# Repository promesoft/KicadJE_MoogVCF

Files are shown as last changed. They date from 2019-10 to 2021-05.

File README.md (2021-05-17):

# KicadJE_MoogVCF
Based on https://www.yusynth.net/Modular/Commun/MOOGVCF/Moogfilter-sch.jpg

Based on https://www.yusynth.net/Modular/Commun/WAVEFOLDER/new/JHWavefolder-sch.gif

Based on https://www.yusynth.net/Modular/Commun/ADSR/ADSR555-FINAL.gif

# Status - PCB  in the mail
## Initial 
| Stage  | Detail | Status |
| --- | --- | --- |
| create material  | sch/pcb | OK  |
| | gerber | OK |
| production  | | Ok |
|  | produced | OK |
|  | delivered | Ok |
## Preliminary validation
| Test  | Detail | Status |
| --- | --- | --- |
| Initial Inspection | | OK - silk messed a bit |
| Initial Technical Test | VCF | CV2 signal issue round Jack |
| Initial Technical Test | ADSR | OK |
| Initial Technical Test | WaveFolder | OK |
| Initial Product Test | VCF | Not working due to missing Caps |
| Initial Product Test | ADSR | OK |
| Initial Product Test | Wavefolder | Works nicely |

## Secondary validation
| Test  | Detail | Status |
| --- | --- |--- |
| Product Test | CF | VCF - working ok after botch'ed caps added - no self osc|
| Product Test | ADSR | Works fine after added 100k resistors instead of 0R across 100KB pots |
| Product Test | Wavefolder | nice - no adjustments |
| Quality | VCF | Needs tweaking |
| Quality | ADSR | ADSR interacts when turned all the way down|
| Quality | Wavefolder| Nice |
| Long Term Product Test |  |  |
| Power Draw | VCF | 24mA |
| Power Draw | ADSR | mA |
| Power Draw | Wavefolder | 7mA |

## Errata
### Errata - VCF
 * Missing signal path for CV2 on PCB
 * Missing 2 caps from C207 to R226/227

## Issues and Notes
### VCF
* C214 should be 1206 (its a bit difficult to find 22u 0805 in 16v)
* C211 and C212 should be 1206 or bigger (10u 16v potentially sounds better than 0805)

# Pictures
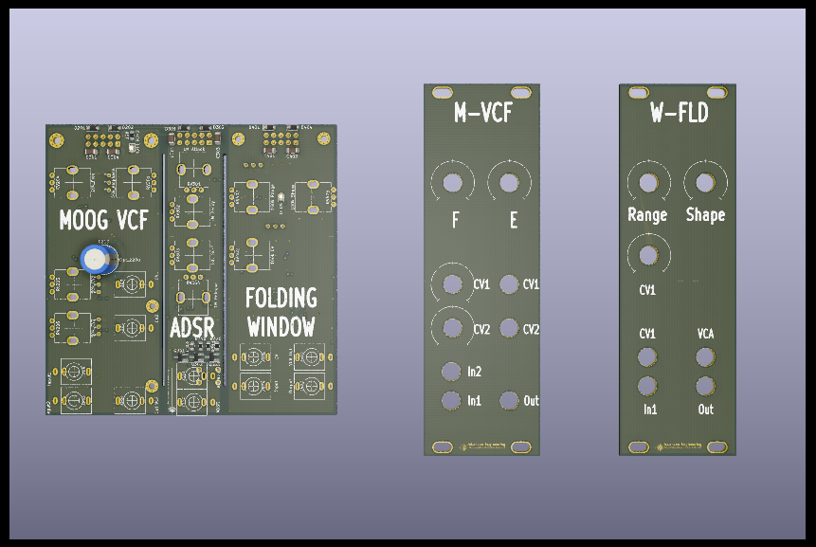
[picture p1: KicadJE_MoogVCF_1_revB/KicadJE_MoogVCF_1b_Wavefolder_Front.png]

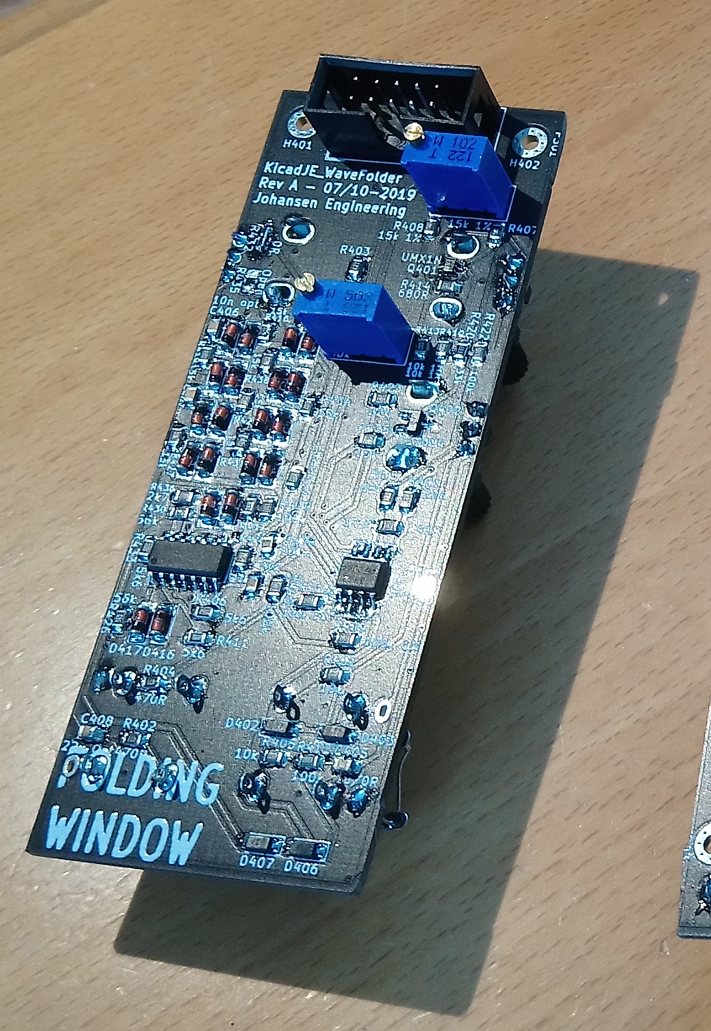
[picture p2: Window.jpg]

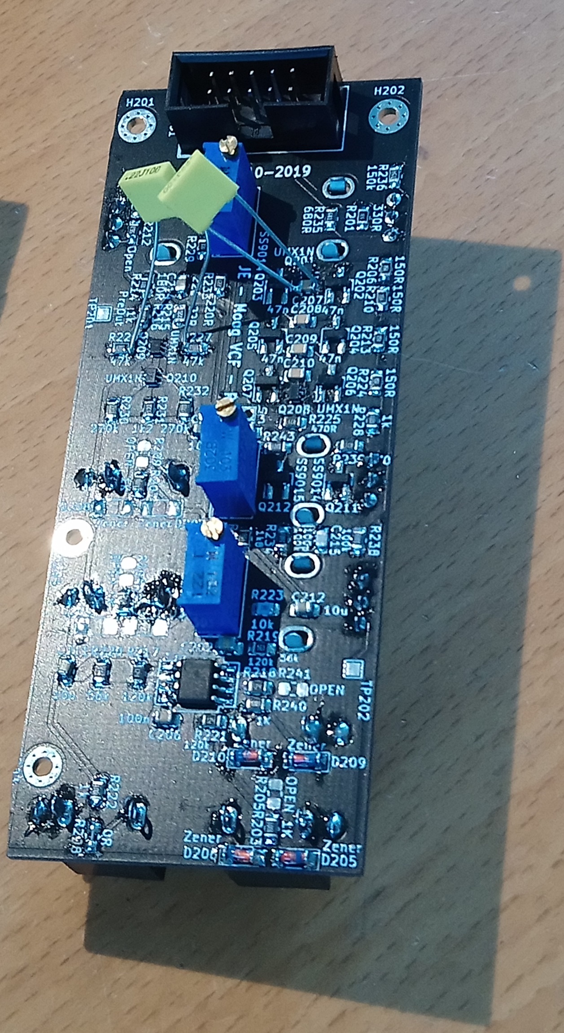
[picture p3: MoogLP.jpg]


# Inspiration

# Schematic
## Ladder Filter
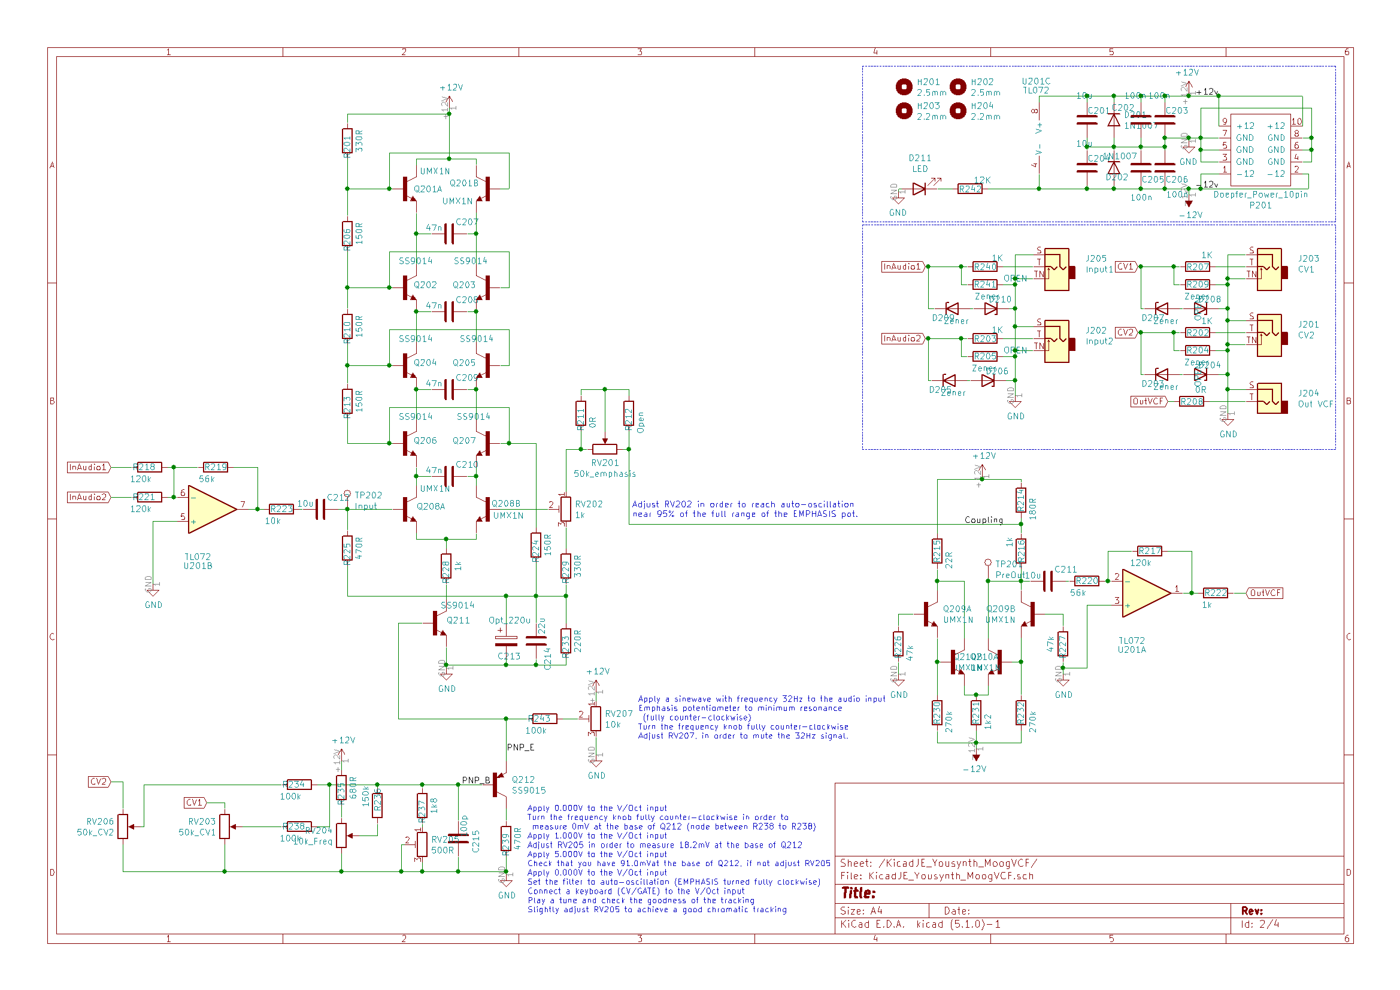
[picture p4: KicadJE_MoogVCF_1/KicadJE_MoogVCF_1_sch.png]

## Simple 555 ADSR
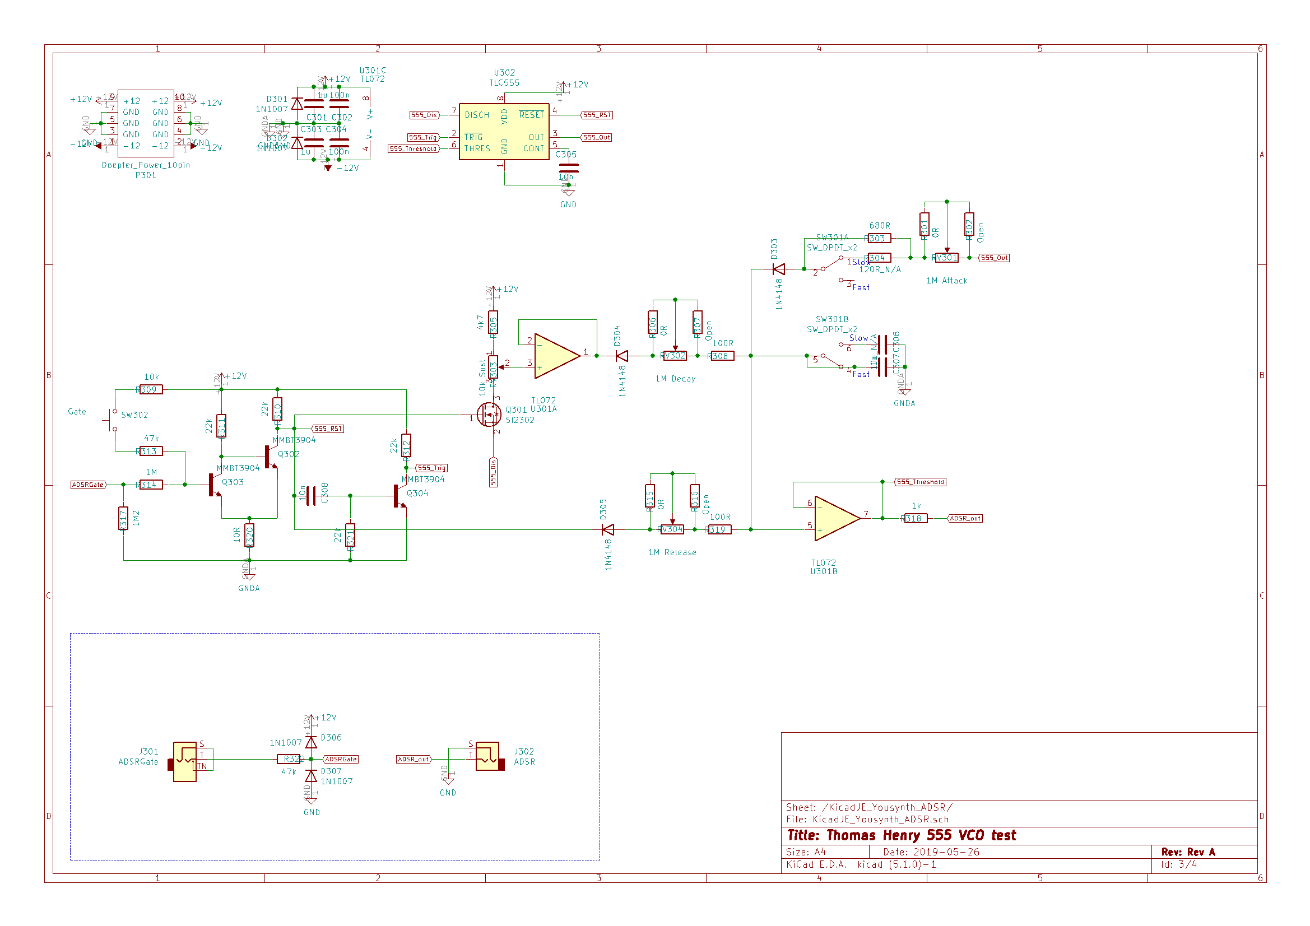
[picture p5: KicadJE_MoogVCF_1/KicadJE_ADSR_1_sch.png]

## WaveFolder
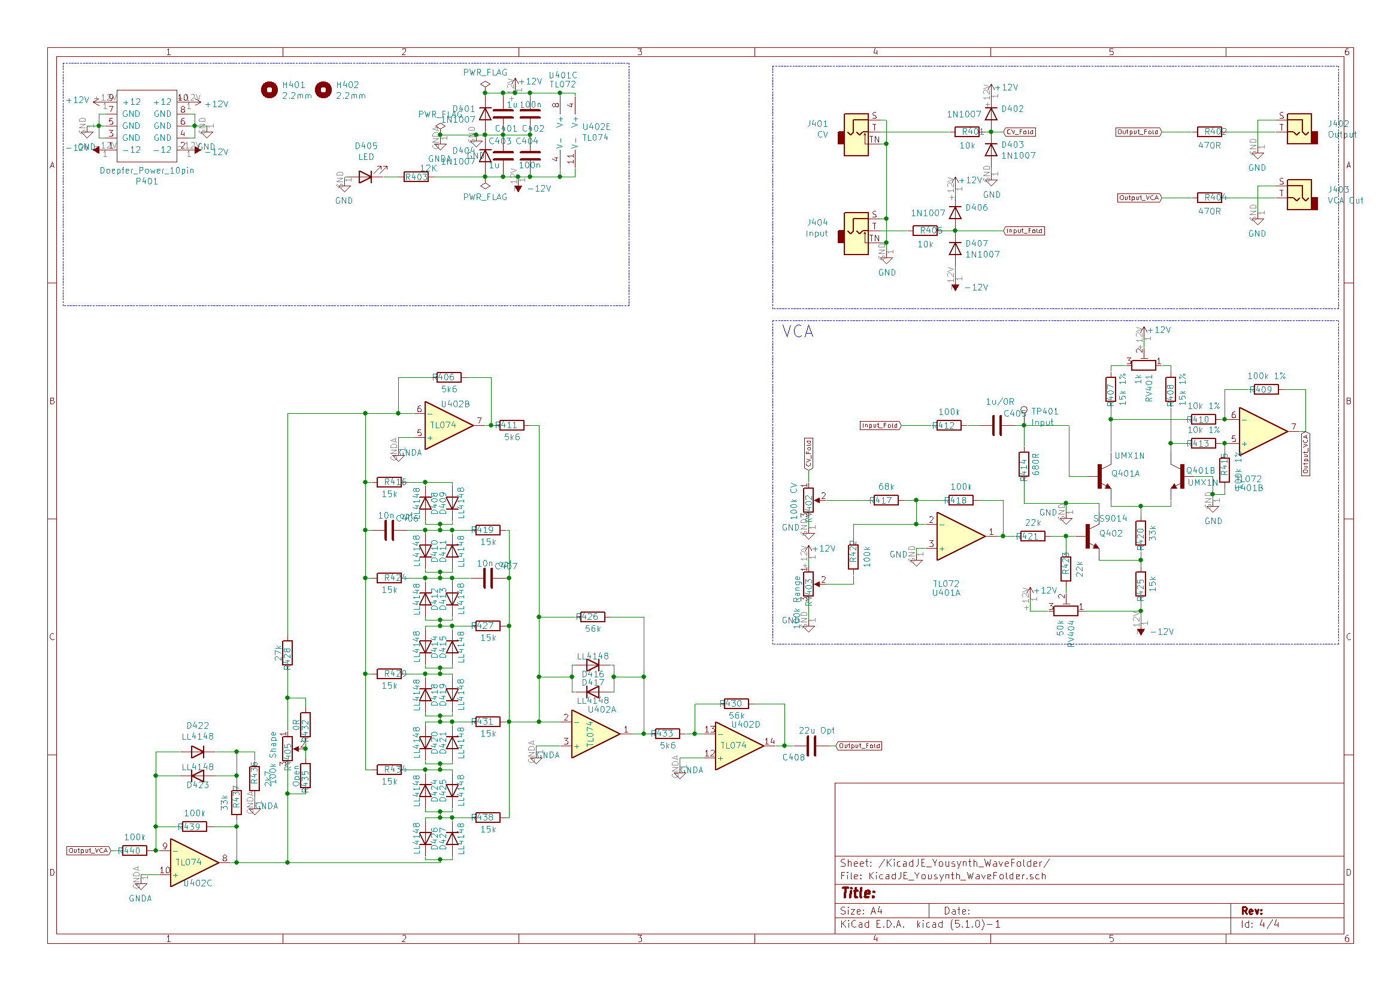
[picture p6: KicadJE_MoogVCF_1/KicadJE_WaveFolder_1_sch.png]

# Inspiration
 http://jhaible.com/legacy/jh_shaper_B.pdf
 
 https://www.yusynth.net/Modular/Commun/WAVEFOLDER/new/JHWavefolder-sch.gif

 https://www.yusynth.net/Modular/Commun/MOOGVCF/Moogfilter-sch.jpg

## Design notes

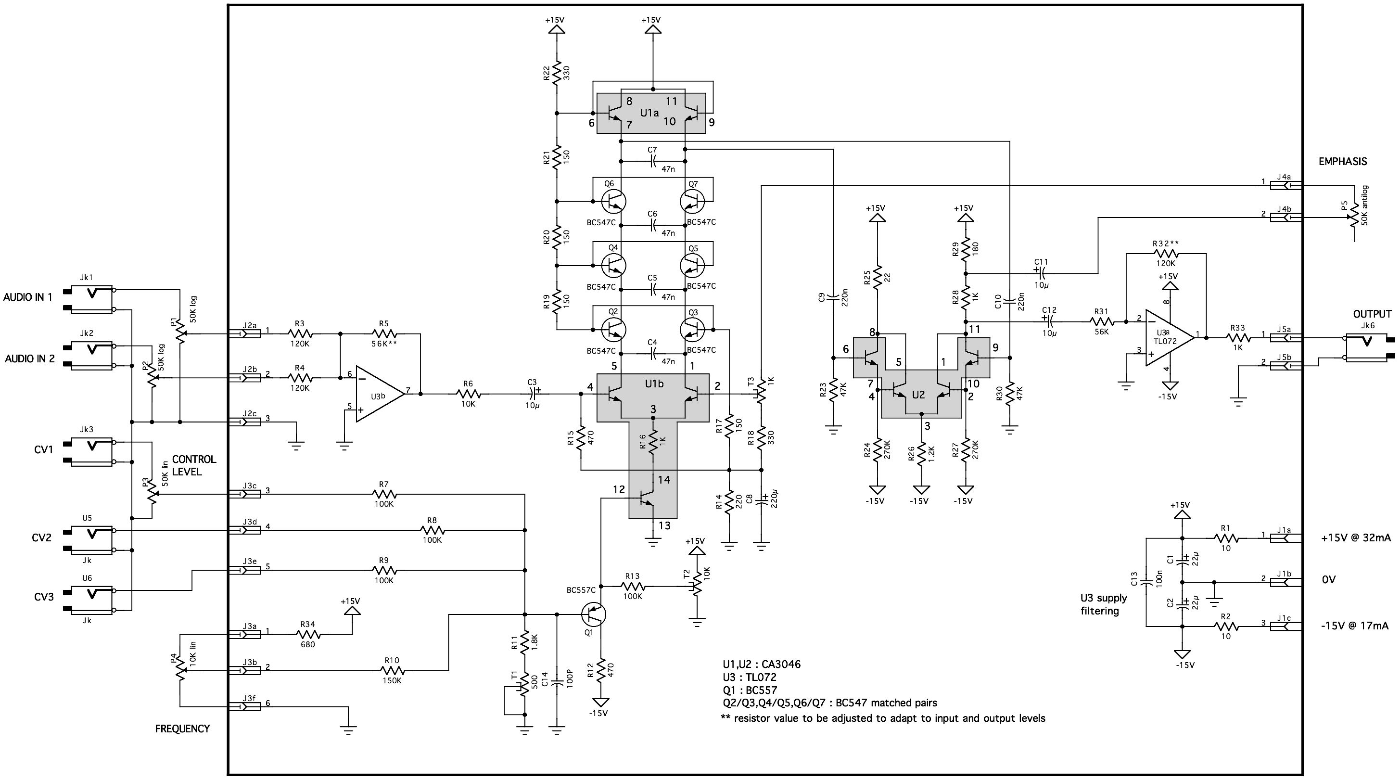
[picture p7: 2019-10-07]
Moogfilter-sch.jpg

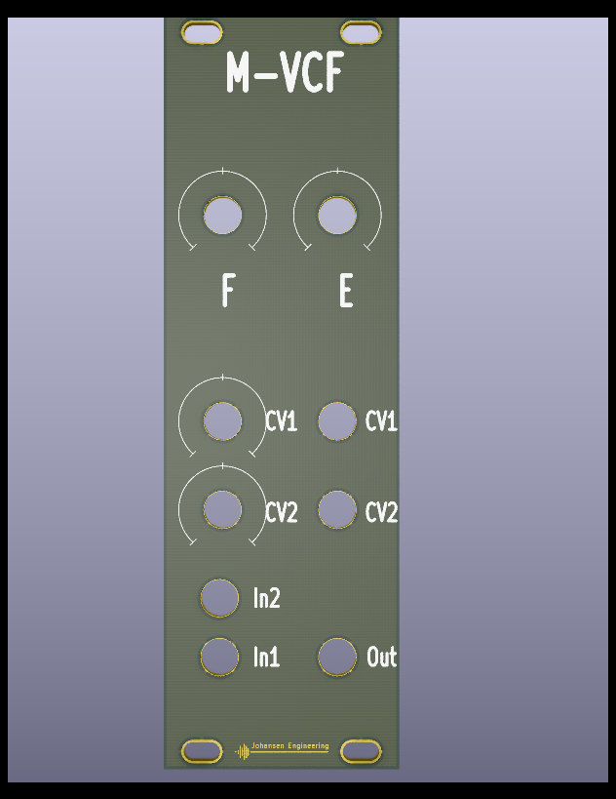
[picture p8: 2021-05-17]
KicadJE_MoogVCF_1_revB/KicadJE_MoogVCF_1b_Face.png

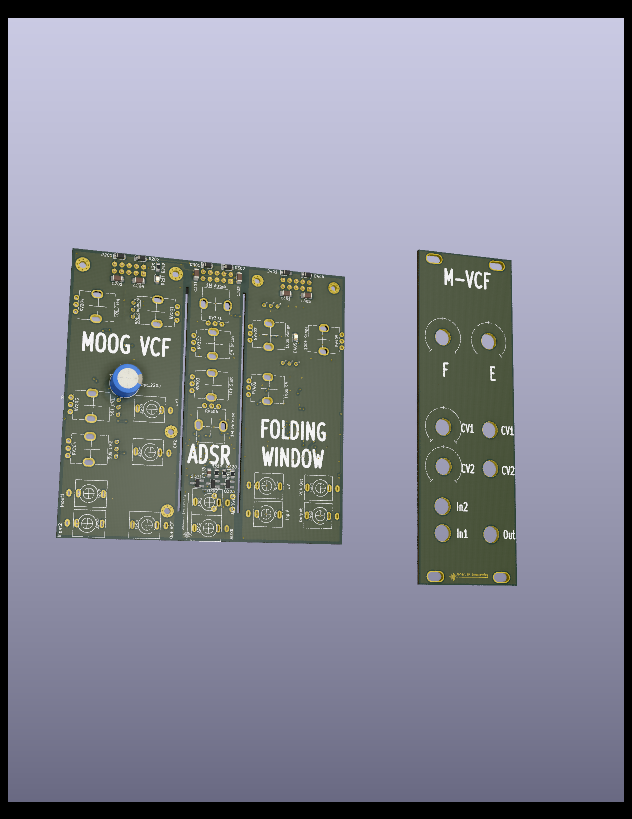
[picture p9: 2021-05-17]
KicadJE_MoogVCF_1_revB/KicadJE_MoogVCF_1b_Front.png

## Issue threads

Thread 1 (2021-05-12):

Faceplate / Panel?

Yulquen, 2021-05-12:
This design looks really good but may I ask if you have ever made a faceplate/panel for it?
Thanks
Florent

promesoft, 2021-05-17:
Hi Florent

Thanks for the feedback.
For this I have not prepared a faceplate, as I am not 100% satisfied with the layout yet (see issues and errata).

Furthermore I have started to migrate towards a more standardized panel based on :
[CV Util](https://github.com/promesoft/KicadJE_Util/blob/master/KicadJE_Util_RevA/KicadJE_Util_All_Front.png)

This is an 8HE panel module (like the Filter and Wavefolder) - it has 2x2 adjustments in the top - then 2x2 inputs and 2x2 outputs in the bottom

promesoft, 2021-05-17:
I've made a preliminary faceplate that can be seen here:
https://github.com/promesoft/KicadJE_MoogVCF/blob/master/README.md

Yulquen, 2021-05-17:
Many thanks for your reactivity. But actually I was more interested by the Wavefolder :) But I should learn KiCAD and make it instead of annoying everybody ;)

promesoft, 2021-05-17:
:) - The wavefolder works as is - so it would make more sense at the moment.

And yes - I'd recommend Kicad - its not so hard if you know a bit abt electronics to start with.
If you stick to analogue synth design its not that hard - they are low voltage - low current - not very noise sensitive - not very EMC radiating - so you can do a lot with simple skills.

I have prepared a new faceplate that matches the eurorack template and the holes for the wavefolder (check out the update on the readme.md.

as for making gerber files its quite simple - just press plot and select these settings for JLC (they have a guide for it online)

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

then generate plot, map and drill files, zip them and upload them to JLC.
Inspect that the PCB looks the same as in Kicad and order....pretty easy.

promesoft, 2021-05-17:
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

promesoft, 2021-05-18:
Let me know if you need help

Yulquen, 2021-05-19:
It looks great, MANY THANKS!

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

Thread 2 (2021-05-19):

Diode values for D401,D402,D403,D404,D406,D407 in the Wave Folder

Yulquen, 2021-05-19:
It's me again.

the diode value for D401,D402,D403,D404,D406,D407 is **1N1007** according KiCAD files.

I think it is meant **1N4007** instead?

promesoft, 2021-05-19:
These are 1N4007 used for input protection. So if you do not have them you can replace them with 1N5817 or similar (or live without input protection)

https://github.com/promesoft/KicadJE_MoogVCF/blob/master/KicadJE_MoogVCF_1/KicadJE_WaveFolder_1_sch.png

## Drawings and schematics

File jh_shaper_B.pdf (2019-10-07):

## JH. Wave Multiplier B

## (c) J. Haible 2001

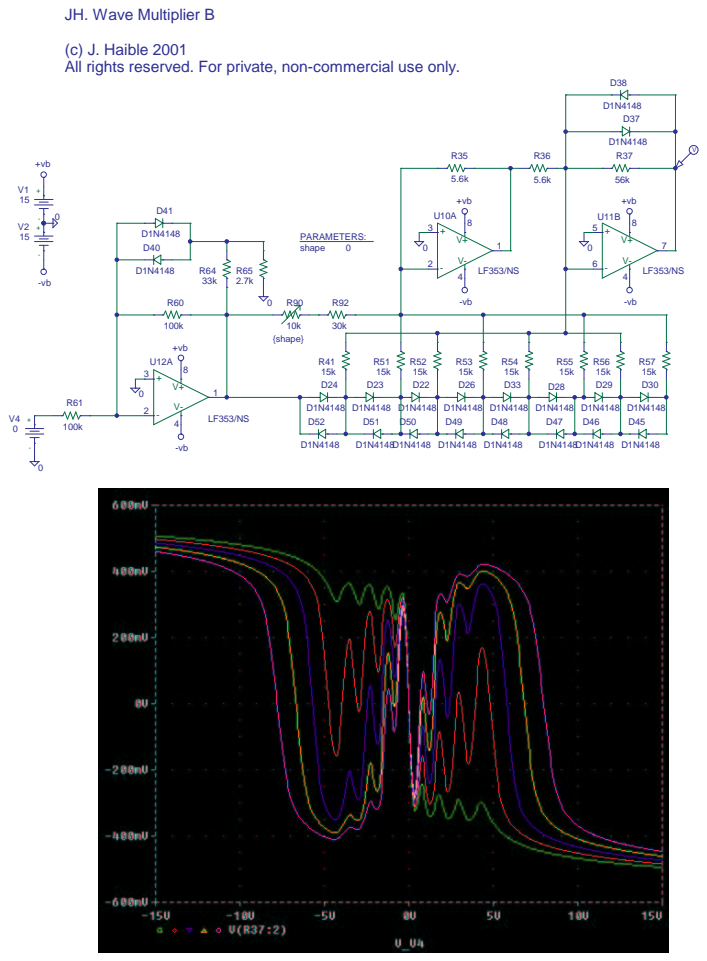
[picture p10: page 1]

All rights reserved. For private, non-commercial use only.

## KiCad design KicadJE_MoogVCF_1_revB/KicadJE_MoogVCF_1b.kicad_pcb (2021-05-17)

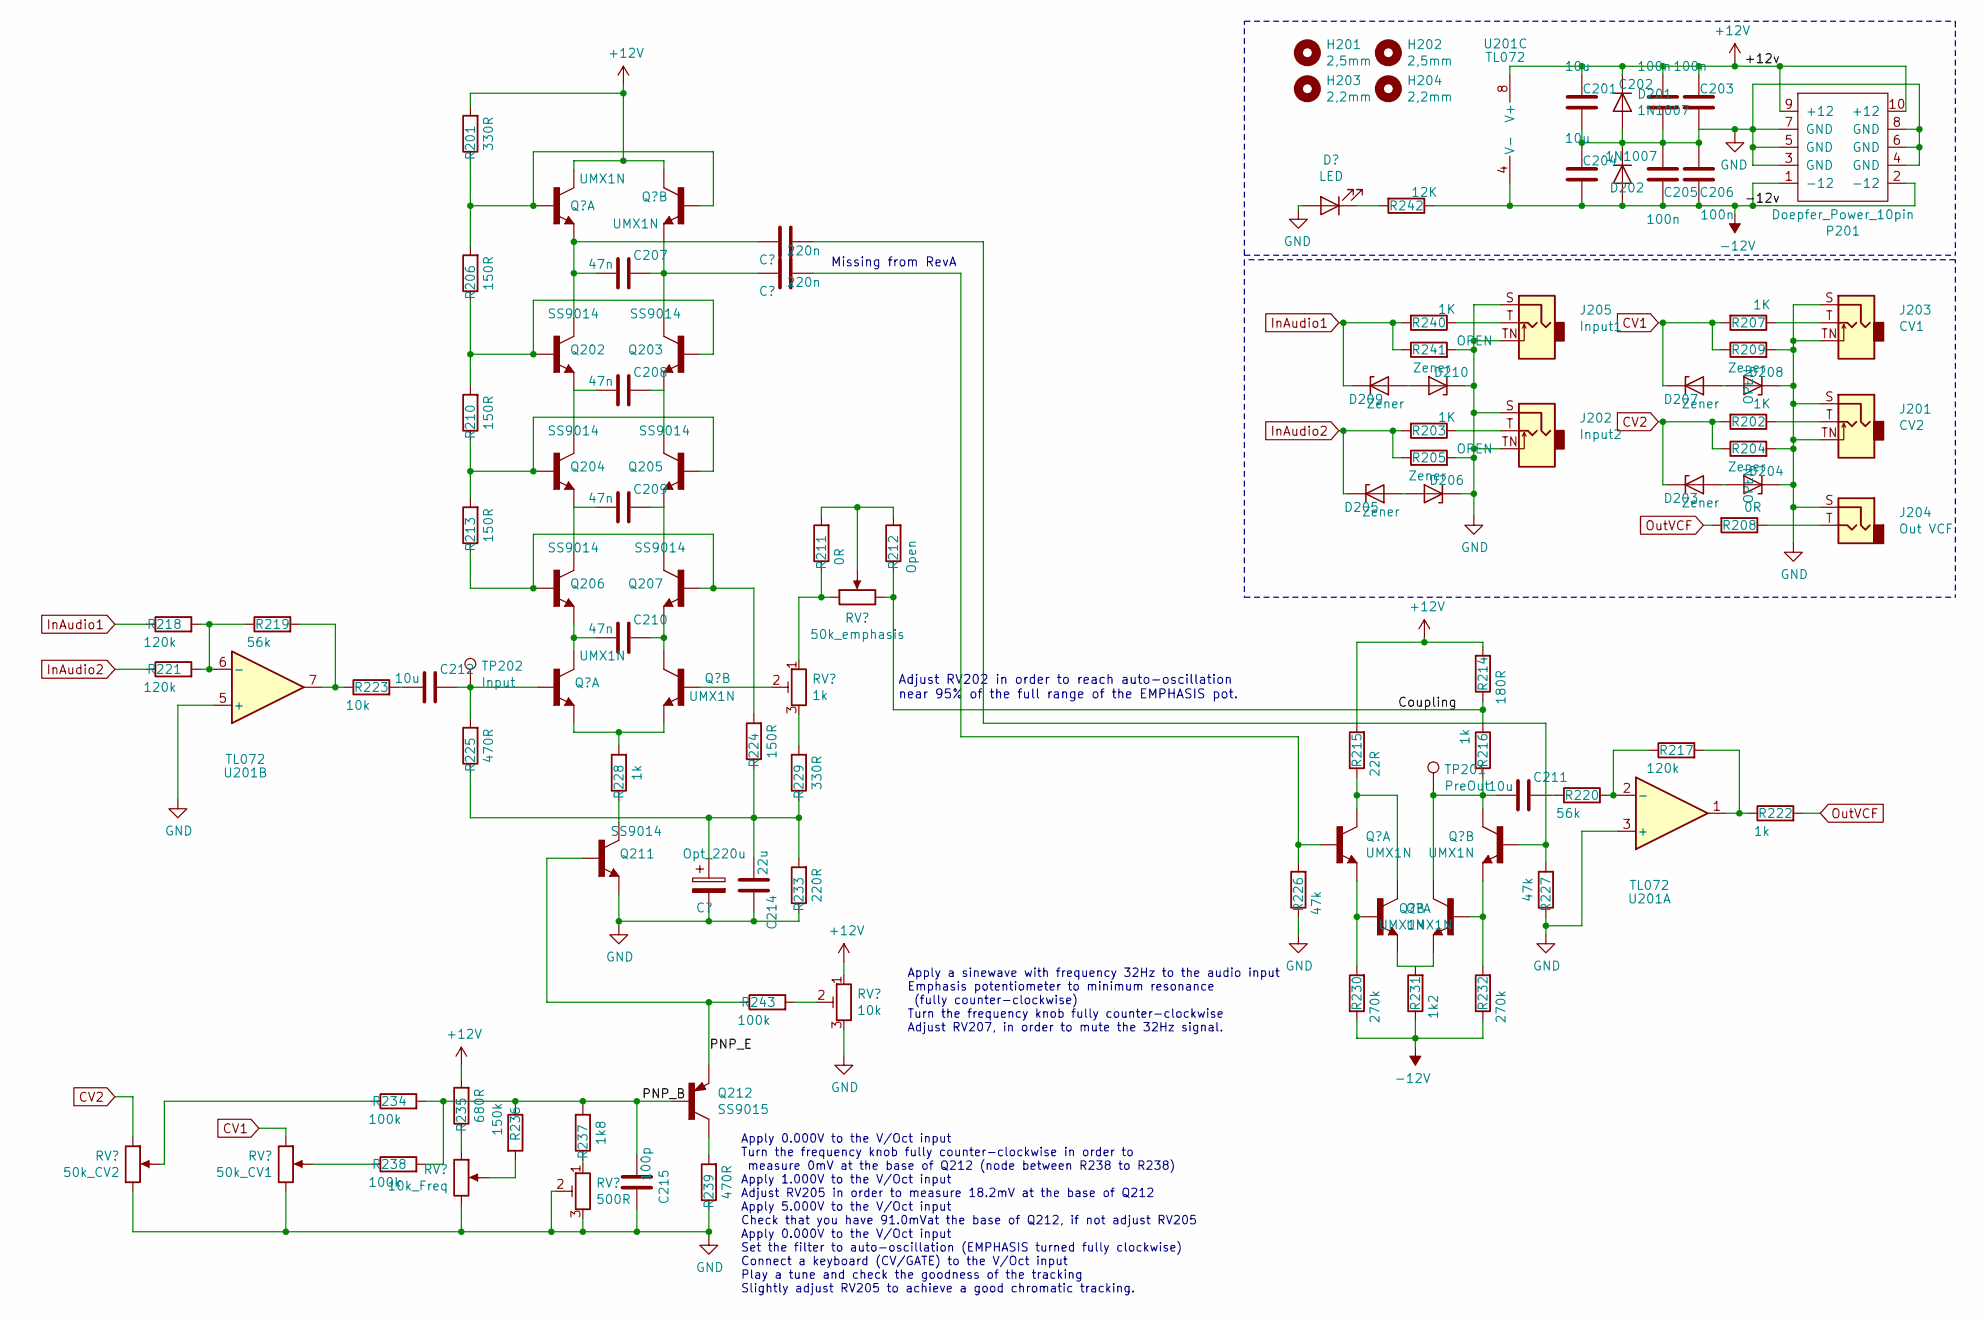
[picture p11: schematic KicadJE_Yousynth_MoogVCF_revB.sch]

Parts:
C201, C204: 10u; C_1206_3216Metric_Pad1.42x1.75mm_HandSolder
C202, C203, C205, C206: 100n; C_0805_2012Metric_Pad1.15x1.40mm_HandSolder
C207, C208, C209, C210: 47n; C_0805_2012Metric_Pad1.15x1.40mm_HandSolder
C211, C212: 10u; C_0805_2012Metric_Pad1.15x1.40mm_HandSolder
C214: 22u; C_0805_2012Metric_Pad1.15x1.40mm_HandSolder
C215: 100p; C_0805_2012Metric_Pad1.15x1.40mm_HandSolder
D201, D202: 1N1007; D_SOD-123
D203, D204, D205, D206, D207, D208, D209, D210: Zener; D_MiniMELF
H201, H202: 2,5mm; MountingHole_2.5mm_Pad_Via
H203, H204: 2,2mm; MountingHole_2.2mm_M2_Pad_Via
J201: CV2; PJ301SM
J202: Input2; PJ301SM
J203: CV1; PJ301SM
J204: Out VCF; PJ301SM
J205: Input1; PJ301SM
P201: Doepfer_Power_10pin; IDC-Header_2x05_Pitch2.54mm_Straight
Q202, Q203, Q204, Q205, Q206, Q207, Q211: SS9014; SOT-23_Handsoldering
Q212: SS9015; SOT-23_Handsoldering
R201, R229: 330R; R_0805_2012Metric_Pad1.15x1.40mm_HandSolder
R202, R203, R207, R240: 1K; R_0805_2012Metric_Pad1.15x1.40mm_HandSolder
R204, R205, R209, R241: OPEN; R_0805_2012Metric_Pad1.15x1.40mm_HandSolder
R206, R210, R213, R224: 150R; R_0805_2012Metric_Pad1.15x1.40mm_HandSolder
R208, R211: 0R; R_0805_2012Metric_Pad1.15x1.40mm_HandSolder
R212: Open; R_0805_2012Metric_Pad1.15x1.40mm_HandSolder
R214: 180R; R_0805_2012Metric_Pad1.15x1.40mm_HandSolder
R215: 22R; R_0805_2012Metric_Pad1.15x1.40mm_HandSolder
R216, R222, R228: 1k; R_0805_2012Metric_Pad1.15x1.40mm_HandSolder
R217, R218, R221: 120k; R_0805_2012Metric_Pad1.15x1.40mm_HandSolder
R219, R220: 56k; R_0805_2012Metric_Pad1.15x1.40mm_HandSolder
R223: 10k; R_0805_2012Metric_Pad1.15x1.40mm_HandSolder
R225, R239: 470R; R_0805_2012Metric_Pad1.15x1.40mm_HandSolder
R226, R227: 47k; R_0805_2012Metric_Pad1.15x1.40mm_HandSolder
R230, R232: 270k; R_0805_2012Metric_Pad1.15x1.40mm_HandSolder
R231: 1k2; R_0805_2012Metric_Pad1.15x1.40mm_HandSolder
R233: 220R; R_0805_2012Metric_Pad1.15x1.40mm_HandSolder
R234, R238, R243: 100k; R_0805_2012Metric_Pad1.15x1.40mm_HandSolder
R235: 680R; R_0805_2012Metric_Pad1.15x1.40mm_HandSolder
R236: 150k; R_0805_2012Metric_Pad1.15x1.40mm_HandSolder
R237: 1k8; R_0805_2012Metric_Pad1.15x1.40mm_HandSolder
R242: 12K; R_0805_2012Metric_Pad1.15x1.40mm_HandSolder
TP201: PreOut; TestPoint_Pad_1.5x1.5mm
TP202: Input; TestPoint_Pad_1.5x1.5mm
U201: TL072; AJ_SO-8_5.3x6.2mm_P1.27mm

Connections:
+12V: C201.2, C202.2, C203.2, D201.1 (K), P201.9 (+12), P201.10 (+12), R201.2, R214.2, R215.2, R235.2, U201.8 (V+); also elsewhere on the board
-12V: C204.1, C205.1, C206.1, D202.2 (A), P201.1 (-12), P201.2 (-12), R230.1, R231.1, R232.1, R242.1, U201.4 (V-); also elsewhere on the board
/KicadJE_Yousynth_MoogVCF/Coupling: R212.1, R214.1, R216.1; also elsewhere on the board
/KicadJE_Yousynth_MoogVCF/PNP_B: C215.2, Q212.1 (B), R234.2, R236.1, R237.2, R238.2
/KicadJE_Yousynth_MoogVCF/PNP_E: Q211.1 (B), Q212.2 (E), R243.1
CV1: D207.1 (K), R207.2, R209.1; also elsewhere on the board
CV2: D203.1 (K), R202.2, R204.1; also elsewhere on the board
GND: C201.1, C202.1, C203.1, C204.2, C205.2, C206.2, C214.1, C215.1, D201.2 (A), D202.1 (K), D204.1 (K), D206.1 (K), D208.1 (K), D210.1 (K), J201.S, J201.TN, J202.S, J202.TN, J203.S, J203.TN, J204.S, J205.S, J205.TN, P201.3 (GND), P201.4 (GND), P201.5 (GND), P201.6 (GND), P201.7 (GND), P201.8 (GND), Q211.2 (E), R204.2, R205.2, R209.2, R226.1, R227.1, R233.1, R239.1, R241.2, U201.3 (+), U201.5 (+); also elsewhere on the board
InAudio1: D209.1 (K), R218.1, R240.2, R241.1
InAudio2: D205.1 (K), R203.2, R205.1, R221.1
unnamed 19: C207.1, Q203.3 (C); also elsewhere on the board
unnamed 20: C207.2, Q202.3 (C); also elsewhere on the board
unnamed: C208.1, Q203.2 (E), Q205.3 (C)
unnamed: C208.2, Q202.2 (E), Q204.3 (C)
unnamed: C209.1, Q205.2 (E), Q207.3 (C)
unnamed: C209.2, Q204.2 (E), Q206.3 (C)
unnamed 25: C210.1, Q207.2 (E); also elsewhere on the board
unnamed 26: C210.2, Q206.2 (E); also elsewhere on the board
unnamed: C211.1, R220.1
unnamed 28: C211.2, R216.2, TP201.1; also elsewhere on the board
unnamed 29: C212.1, R225.2, TP202.1; also elsewhere on the board
unnamed: C212.2, R223.2
unnamed 31: C214.2, R224.1, R225.1, R229.1, R233.2; also elsewhere on the board
unnamed: D203.2 (A), D204.2 (A)
unnamed: D205.2 (A), D206.2 (A)
unnamed: D207.2 (A), D208.2 (A)
unnamed: D209.2 (A), D210.2 (A)
unnamed 46: R242.2; also elsewhere on the board
unnamed: J201.T, R202.1
unnamed: J202.T, R203.1
unnamed: J203.T, R207.1
unnamed: J204.T, R208.1
unnamed: J205.T, R240.1
unnamed 73: R201.1, R206.2; also elsewhere on the board
unnamed: Q202.1 (B), Q203.1 (B), R206.1, R210.2
unnamed: Q204.1 (B), Q205.1 (B), R210.1, R213.2
unnamed: Q206.1 (B), Q207.1 (B), R213.1, R224.2
unnamed 77: R228.2; also elsewhere on the board
unnamed 79: R230.2; also elsewhere on the board
unnamed 80: R226.2; also elsewhere on the board
unnamed 81: R232.2; also elsewhere on the board
unnamed 82: R227.2; also elsewhere on the board
unnamed 83: R215.1; also elsewhere on the board
unnamed 84: R231.2; also elsewhere on the board
unnamed: Q211.3 (C), R228.1
unnamed: Q212.3 (C), R239.2
unnamed 96: R211.1; also elsewhere on the board
unnamed 97: R211.2, R212.2; also elsewhere on the board
unnamed: R217.1, R220.2, U201.2 (-)
unnamed: R217.2, R222.1, U201.1
unnamed: R218.2, R219.1, R221.2, U201.6 (-)
unnamed: R219.2, R223.1, U201.7
unnamed 102: R229.2; also elsewhere on the board
unnamed 103: R234.1; also elsewhere on the board
unnamed 104: R235.1; also elsewhere on the board
unnamed 105: R236.2; also elsewhere on the board
unnamed 106: R237.1; also elsewhere on the board
unnamed 107: R238.1; also elsewhere on the board
unnamed 108: R243.2; also elsewhere on the board
OutVCF: R208.2, R222.2

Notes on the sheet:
Apply a sinewave with frequency 32Hz to the audio input Emphasis potentiometer to minimum resonance (fully counter-clockwise) Turn the frequency knob fully counter-clockwise Adjust RV207, in order to mute the 32Hz signal.
Adjust RV202 in order to reach auto-oscillation near 95% of the full range of the EMPHASIS pot.
Apply 0.000V to the V/Oct input Turn the frequency knob fully counter-clockwise in order to measure 0mV at the base of Q212 (node between R238 to R238) Apply 1.000V to the V/Oct input Adjust RV205 in order to measure 18.2mV at the base of Q212 Apply 5.000V to the V/Oct input Check that you have 91.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
Missing from RevA

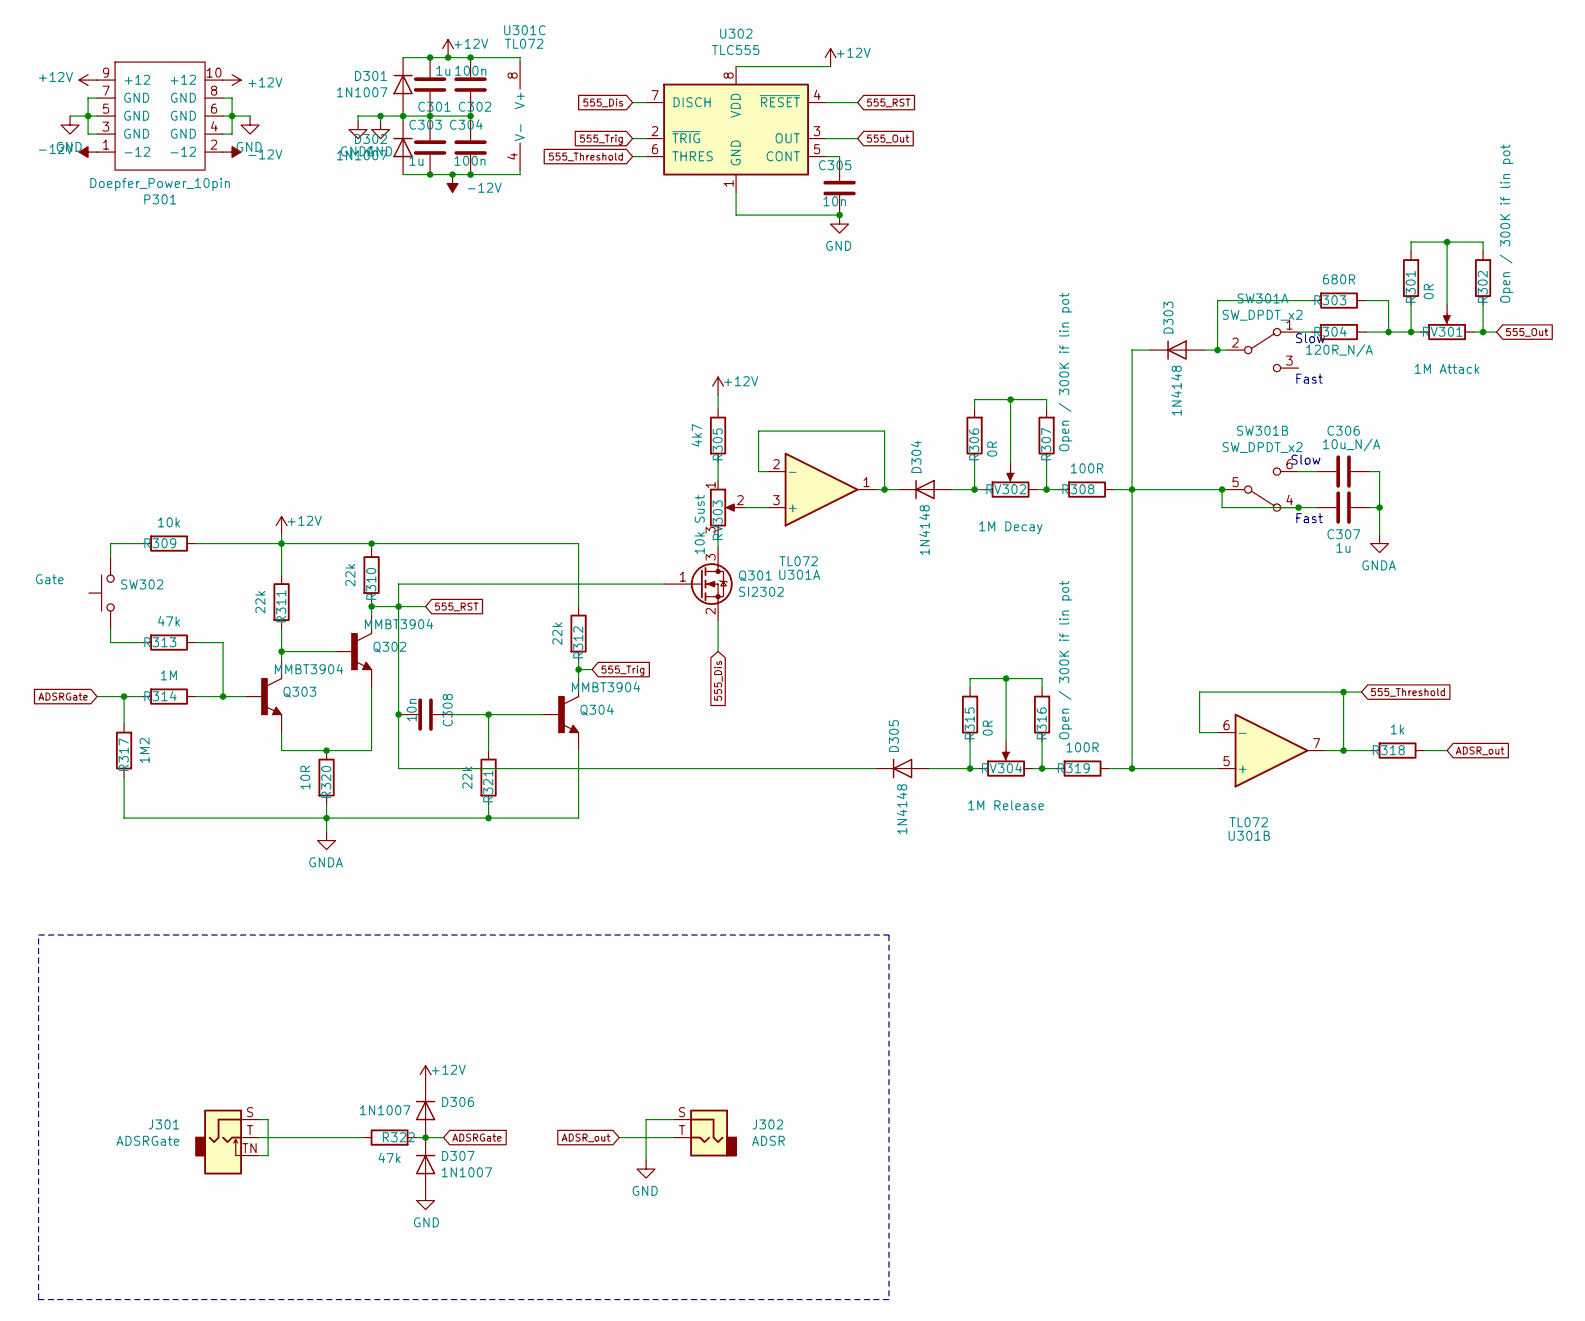
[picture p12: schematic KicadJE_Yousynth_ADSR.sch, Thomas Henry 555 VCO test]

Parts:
C301, C303: 1u; C_1206_3216Metric_Pad1.42x1.75mm_HandSolder
C302, C304: 100n; C_0805_2012Metric_Pad1.15x1.40mm_HandSolder
C305, C308: 10n; C_0805_2012Metric_Pad1.15x1.40mm_HandSolder
C306: 10u_N/A; C_0805_2012Metric_Pad1.15x1.40mm_HandSolder
C307: 1u; C_0805_2012Metric_Pad1.15x1.40mm_HandSolder
D301, D302, D306, D307: 1N1007; D_SOD-123
D303, D304, D305: 1N4148; D_SOD-123
J301: ADSRGate; PJ301SM
J302: ADSR; PJ301SM
P301: Doepfer_Power_10pin; IDC-Header_2x05_Pitch2.54mm_Straight
Q301: SI2302; SOT-23_Handsoldering
Q302, Q303, Q304: MMBT3904; SOT-23_Handsoldering
R301, R306, R315: 0R; R_0805_2012Metric_Pad1.15x1.40mm_HandSolder
R302, R307, R316: Open / 300K if lin pot; R_0805_2012Metric_Pad1.15x1.40mm_HandSolder
R303: 680R; R_0805_2012Metric_Pad1.15x1.40mm_HandSolder
R304: 120R_N/A; R_0805_2012Metric_Pad1.15x1.40mm_HandSolder
R305: 4k7; R_0805_2012Metric_Pad1.15x1.40mm_HandSolder
R308, R319: 100R; R_0805_2012Metric_Pad1.15x1.40mm_HandSolder
R309: 10k; R_0805_2012Metric_Pad1.15x1.40mm_HandSolder
R310, R311, R312, R321: 22k; R_0805_2012Metric_Pad1.15x1.40mm_HandSolder
R313, R322: 47k; R_0805_2012Metric_Pad1.15x1.40mm_HandSolder
R314: 1M; R_0805_2012Metric_Pad1.15x1.40mm_HandSolder
R317: 1M2; R_0805_2012Metric_Pad1.15x1.40mm_HandSolder
R318: 1k; R_0805_2012Metric_Pad1.15x1.40mm_HandSolder
R320: 10R; R_0805_2012Metric_Pad1.15x1.40mm_HandSolder
RV301: 1M Attack; Potentiometer_China_RK09_Single_Vertical_AJ
RV302: 1M Decay; Potentiometer_China_RK09_Single_Vertical_AJ
RV303: 10k Sust; Potentiometer_China_RK09_Single_Vertical_AJ
RV304: 1M Release; Potentiometer_China_RK09_Single_Vertical_AJ
SW301: SW_DPDT_x2; Johansen_engineering_logo_20mm
SW302: Gate; SW_PUSH_6mm
U301: TL072; AJ_SO-8_5.3x6.2mm_P1.27mm
U302: TLC555; AJ_SO-8_5.3x6.2mm_P1.27mm

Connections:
555_Dis: Q301.2 (S), U302.7 (DISCH)
555_Out: R302.1, RV301.3, U302.3 (OUT)
555_RST: C308.2, D305.1 (K), Q301.1 (G), Q302.3 (C), R310.2, U302.4 (~RESET)
555_Threshold: R318.2, U301.6 (-), U301.7, U302.6 (THRES)
555_Trig: Q304.3 (C), R312.2, U302.2 (~TRIG)
+12V: C301.2, C302.2, D301.1 (K), D306.1 (K), P301.9 (+12), P301.10 (+12), R305.1, R309.1, R310.1, R311.1, R312.1, U301.8 (V+), U302.8 (VDD); also elsewhere on the board
-12V: C303.2, C304.2, D302.2 (A), P301.1 (-12), P301.2 (-12), U301.4 (V-); also elsewhere on the board
ADSRGate: D306.2 (A), D307.1 (K), R314.2, R317.2, R322.2
ADSR_out: J302.T, R318.1
GND: C301.1, C302.1, C303.1, C304.1, C305.2, C306.1, C307.1, D301.2 (A), D302.1 (K), D307.2 (A), J302.S, P301.3 (GND), P301.4 (GND), P301.5 (GND), P301.6 (GND), P301.7 (GND), P301.8 (GND), Q304.2 (E), R317.1, R320.2, R321.2, U302.1 (GND); also elsewhere on the board
unnamed: C305.1, U302.5 (CONT)
unnamed: C307.2, D303.1 (K), R308.1, R319.1, SW301.4 (A), SW301.5 (B), U301.5 (+)
unnamed: C308.1, Q304.1 (B), R321.1
unnamed: D303.2 (A), R303.2, SW301.2 (B)
unnamed: D304.1 (K), U301.1, U301.2 (-)
unnamed: D304.2 (A), R306.1, RV302.1
unnamed: D305.2 (A), R315.1, RV304.1
unnamed: J301.S, J301.TN
unnamed: J301.T, R322.1
unnamed: Q301.3 (D), RV303.3
unnamed: Q302.1 (B), Q303.3 (C), R311.2
unnamed: Q302.2 (E), Q303.2 (E), R320.1
unnamed: Q303.1 (B), R313.1, R314.1
unnamed: R301.1, R303.1, R304.1, RV301.1
unnamed: R301.2, R302.2, RV301.2
unnamed: R305.2, RV303.1
unnamed: R306.2, R307.2, RV302.2
unnamed: R307.1, R308.2, RV302.3
unnamed: R309.2, SW302.2
unnamed: R313.2, SW302.1
unnamed: R315.2, R316.2, RV304.2
unnamed: R316.1, R319.2, RV304.3
unnamed: RV303.2, U301.3 (+)

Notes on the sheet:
Fast
Slow

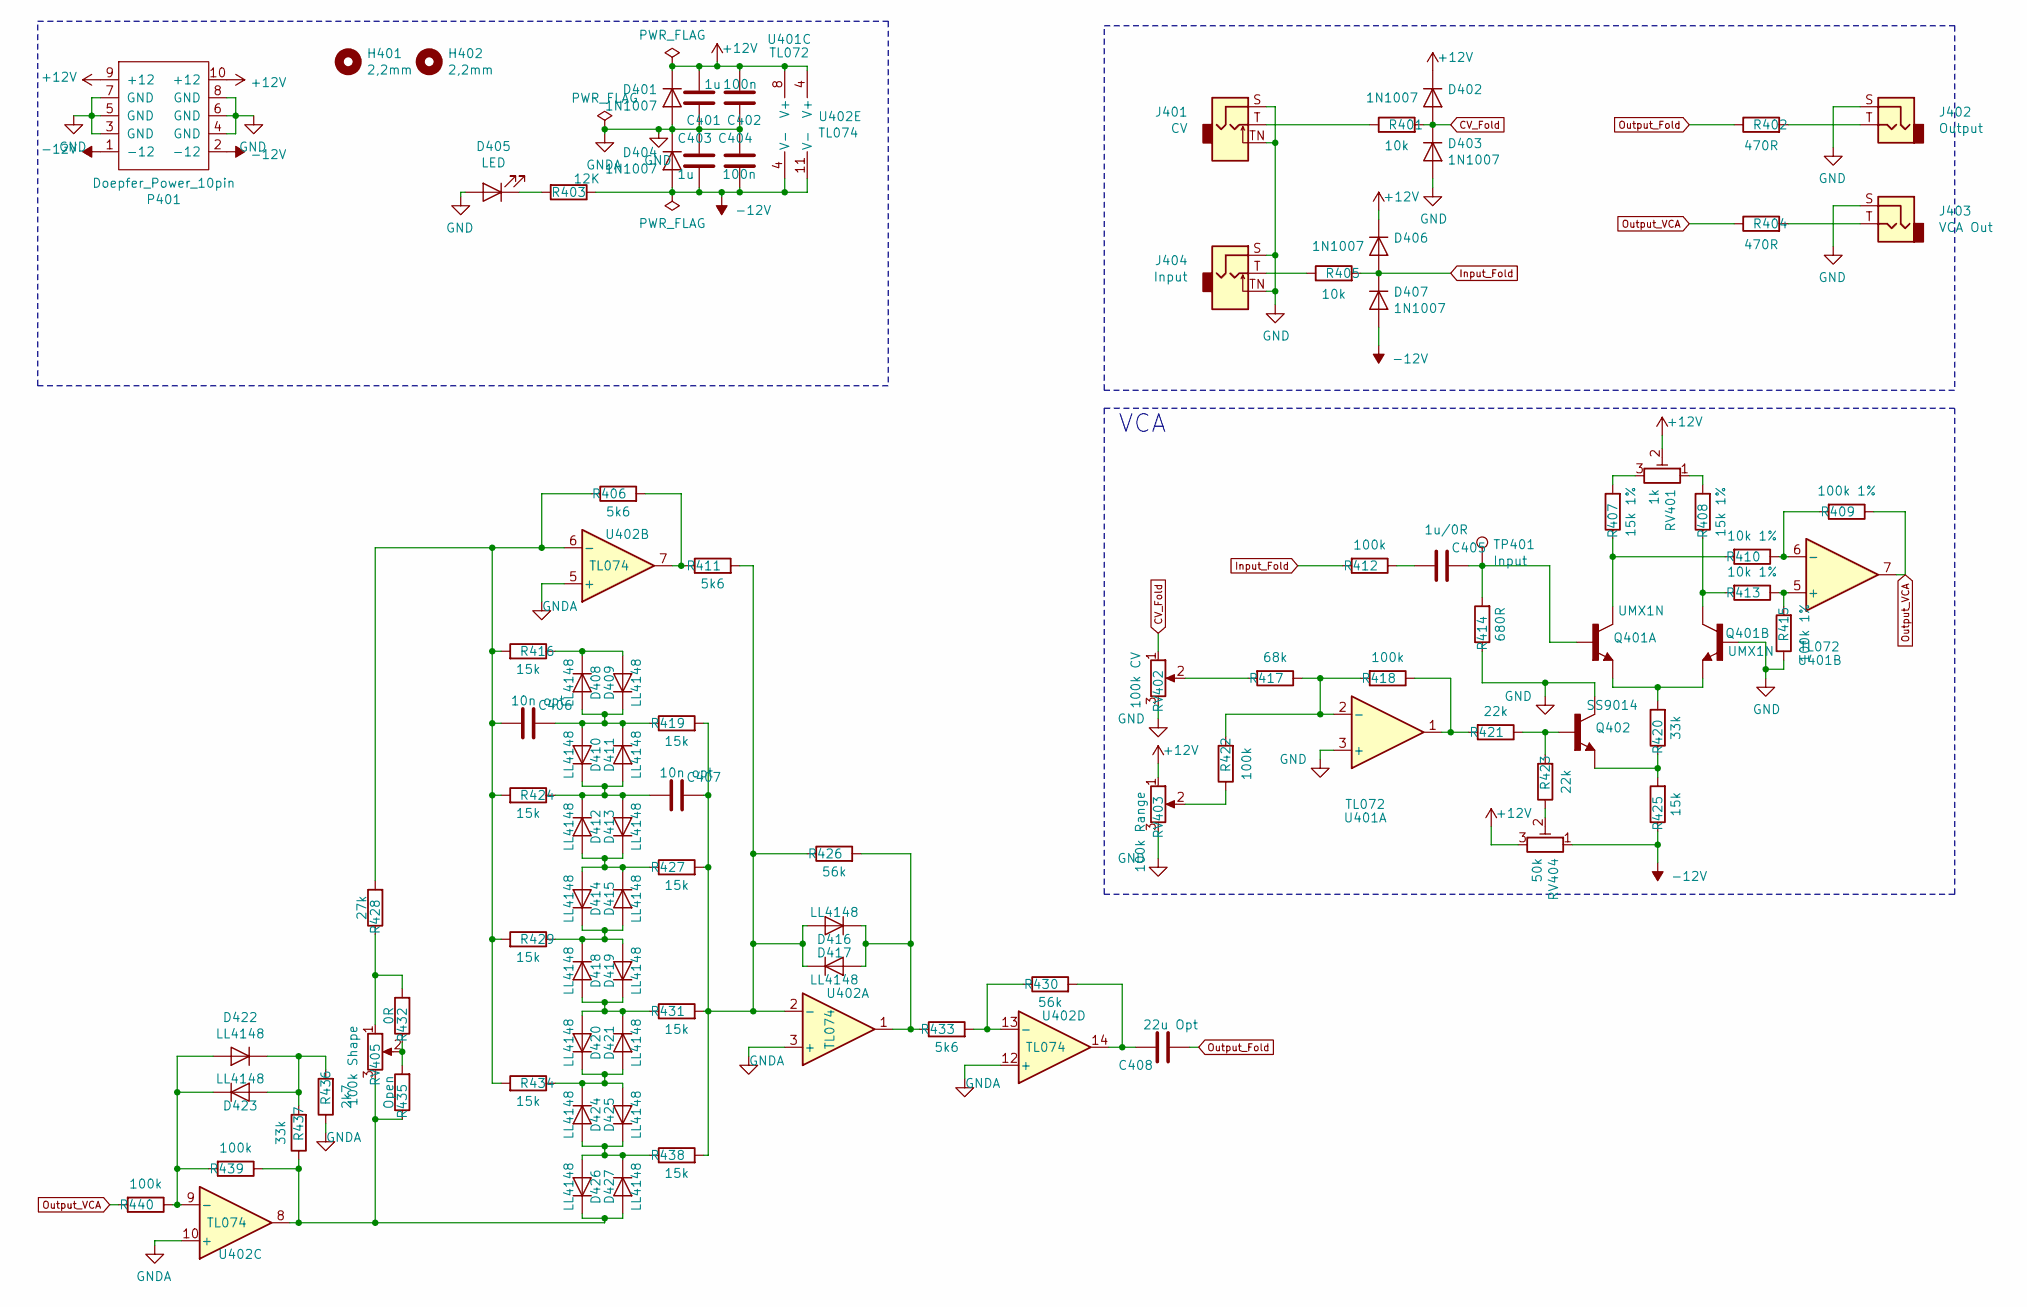
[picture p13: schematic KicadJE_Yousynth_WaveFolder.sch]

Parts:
C401, C403: 1u; C_1206_3216Metric_Pad1.42x1.75mm_HandSolder
C402, C404: 100n; C_0805_2012Metric_Pad1.15x1.40mm_HandSolder
C405: 1u/0R; C_0805_2012Metric_Pad1.15x1.40mm_HandSolder
C406, C407: 10n opt; C_0805_2012Metric_Pad1.15x1.40mm_HandSolder
C408: 22u Opt; C_0805_2012Metric_Pad1.15x1.40mm_HandSolder
D401, D402, D403, D404, D406, D407: 1N1007; D_SOD-123
D405: LED; LED_0805_2012Metric
D408, D409, D410, D411, D412, D413, D414, D415, D416, D417, D418, D419, D420, D421, D422, D423, D424, D425, D426, D427: LL4148; D_MiniMELF
H401, H402: 2,2mm; MountingHole_2.2mm_M2_Pad_Via
J401: CV; PJ301SM
J402: Output; PJ301SM
J403: VCA Out; PJ301SM
J404: Input; PJ301SM
P401: Doepfer_Power_10pin; IDC-Header_2x05_Pitch2.54mm_Straight
Q401: UMX1N; UMX1N_UMT6_DualNPN
Q402: SS9014; SOT-23_Handsoldering
R401, R405: 10k; R_0805_2012Metric_Pad1.15x1.40mm_HandSolder
R402, R404: 470R; R_0805_2012Metric_Pad1.15x1.40mm_HandSolder
R403: 12K; R_0805_2012Metric_Pad1.15x1.40mm_HandSolder
R406, R411, R433: 5k6; R_0805_2012Metric_Pad1.15x1.40mm_HandSolder
R407, R408: 15k 1%; R_0805_2012Metric_Pad1.15x1.40mm_HandSolder
R409, R415: 100k 1%; R_0805_2012Metric_Pad1.15x1.40mm_HandSolder
R410, R413: 10k 1%; R_0805_2012Metric_Pad1.15x1.40mm_HandSolder
R412, R418, R422, R439, R440: 100k; R_0805_2012Metric_Pad1.15x1.40mm_HandSolder
R414: 680R; R_0805_2012Metric_Pad1.15x1.40mm_HandSolder
R416, R419, R424, R425, R427, R429, R431, R434, R438: 15k; R_0805_2012Metric_Pad1.15x1.40mm_HandSolder
R417: 68k; R_0805_2012Metric_Pad1.15x1.40mm_HandSolder
R420, R437: 33k; R_0805_2012Metric_Pad1.15x1.40mm_HandSolder
R421, R423: 22k; R_0805_2012Metric_Pad1.15x1.40mm_HandSolder
R426, R430: 56k; R_0805_2012Metric_Pad1.15x1.40mm_HandSolder
R428: 27k; R_0805_2012Metric_Pad1.15x1.40mm_HandSolder
R432: 0R; R_0805_2012Metric_Pad1.15x1.40mm_HandSolder
R435: Open; R_0805_2012Metric_Pad1.15x1.40mm_HandSolder
R436: 2k7; R_0805_2012Metric_Pad1.15x1.40mm_HandSolder
RV401: 1k; Bourns3296WV
RV402: 100k CV; Potentiometer_China_RK09_Single_Vertical_AJ
RV403: 100k Range; Potentiometer_China_RK09_Single_Vertical_AJ
RV404: 50k; Bourns3296WV
RV405: 100k Shape; Potentiometer_China_RK09_Single_Vertical_AJ
TP401: Input; TestPoint_Pad_1.5x1.5mm
U401: TL072; AJ_SO-8_5.3x6.2mm_P1.27mm
U402: TL074

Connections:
+12V: C401.2, C402.2, D401.1 (K), D402.1 (K), D406.1 (K), P401.9 (+12), P401.10 (+12), RV401.2, RV403.1, RV404.3, U401.8 (V+), U402.4 (V+); also elsewhere on the board
-12V: C403.2, C404.2, D404.2 (A), D407.2 (A), P401.1 (-12), P401.2 (-12), R403.1, R425.1, RV404.1, U401.4 (V-), U402.11 (V-); also elsewhere on the board
CV_Fold: D402.2 (A), D403.1 (K), R401.2, RV402.1
GND: C401.1, C402.1, C403.1, C404.1, D401.2 (A), D403.2 (A), D404.1 (K), D405.2 (A), J401.S, J401.TN, J402.S, J403.S, J404.S, J404.TN, P401.3 (GND), P401.4 (GND), P401.5 (GND), P401.6 (GND), P401.7 (GND), P401.8 (GND), Q401.5 (B), Q402.3 (C), R414.1, R415.1, R436.1, RV402.3, RV403.3, U401.3 (+), U402.3 (+), U402.5 (+), U402.10 (+), U402.12 (+); also elsewhere on the board
Input_Fold: D406.2 (A), D407.1 (K), R405.2, R412.2
unnamed: C405.1, Q401.2 (B), R414.2, TP401.1
unnamed: C405.2, R412.1
unnamed: C406.1, D408.2 (A), D409.1 (K), D410.2 (A), D411.1 (K), R419.1
unnamed: C406.2, R406.1, R416.2, R424.2, R428.2, R429.2, R434.2, U402.6 (-)
unnamed: C407.1, D416.2 (A), D417.1 (K), R411.2, R419.2, R426.1, R427.2, R431.2, R438.2, U402.2 (-)
unnamed: C407.2, D410.1 (K), D411.2 (A), D412.1 (K), D413.2 (A), R424.1
unnamed: C408.1, R430.2, U402.14
unnamed: D405.1 (K), R403.2
unnamed: D408.1 (K), D409.2 (A), R416.1
unnamed: D412.2 (A), D413.1 (K), D414.2 (A), D415.1 (K), R427.1
unnamed: D414.1 (K), D415.2 (A), D418.1 (K), D419.2 (A), R429.1
unnamed: D416.1 (K), D417.2 (A), R426.2, R433.1, U402.1
unnamed: D418.2 (A), D419.1 (K), D420.2 (A), D421.1 (K), R431.1
unnamed: D420.1 (K), D421.2 (A), D424.1 (K), D425.2 (A), R434.1
unnamed: D422.1 (K), D423.2 (A), R436.2, R437.2
unnamed: D422.2 (A), D423.1 (K), R439.2, R440.1, U402.9 (-)
unnamed: D424.2 (A), D425.1 (K), D426.2 (A), D427.1 (K), R438.1
unnamed: D426.1 (K), D427.2 (A), R435.1, R437.1, R439.1, RV405.3, U402.8
unnamed: J401.T, R401.1
unnamed: J402.T, R402.2
unnamed: J403.T, R404.2
unnamed: J404.T, R405.1
unnamed: Q401.1 (E), Q401.4 (E), R420.2
unnamed: Q401.3 (C), R408.1, R413.2
unnamed: Q401.6 (C), R407.1, R410.2
unnamed: Q402.1 (B), R421.1, R423.2
unnamed: Q402.2 (E), R420.1, R425.2
unnamed: R406.2, R411.1, U402.7
unnamed: R407.2, RV401.3
unnamed: R408.2, RV401.1
unnamed: R409.2, R410.1, U401.6 (-)
unnamed: R413.1, R415.2, U401.5 (+)
unnamed: R417.1, R418.2, R422.2, U401.2 (-)
unnamed: R417.2, RV402.2
unnamed: R418.1, R421.2, U401.1
unnamed: R422.1, RV403.2
unnamed: R423.1, RV404.2
unnamed: R428.1, R432.2, RV405.1
unnamed: R430.1, R433.2, U402.13 (-)
unnamed: R432.1, R435.2, RV405.2
Output_Fold: C408.2, R402.1
Output_VCA: R404.1, R409.1, R440.2, U401.7

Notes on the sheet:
VCA

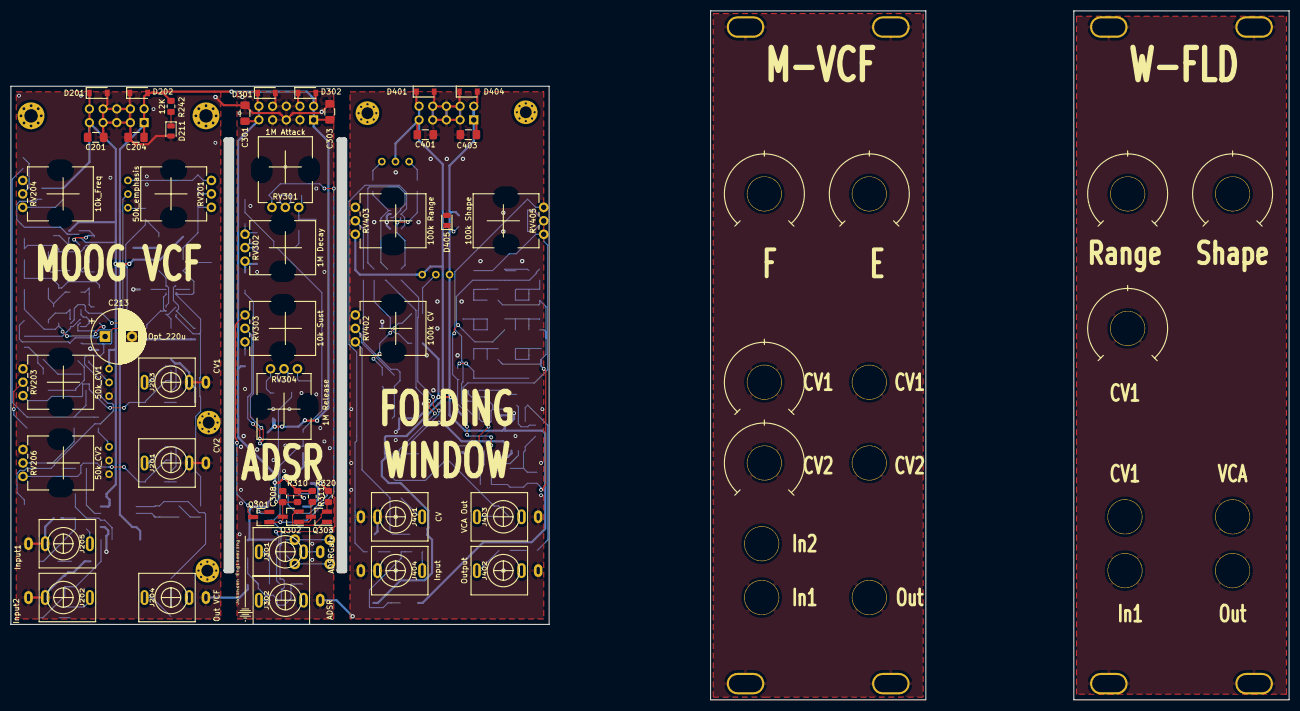
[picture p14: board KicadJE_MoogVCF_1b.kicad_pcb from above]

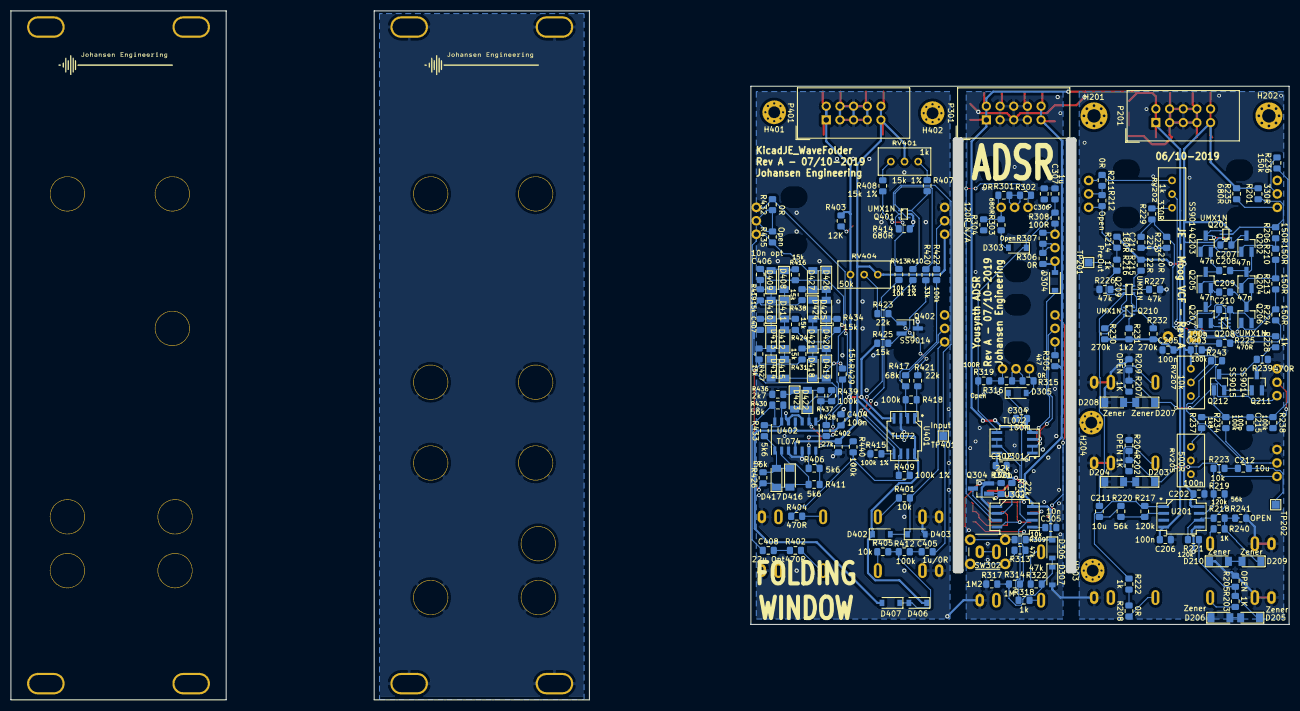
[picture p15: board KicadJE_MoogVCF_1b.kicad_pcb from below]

Board: 2 copper layers, 100.0 x 100.0 mm, 245 parts (199 on the bottom side), 135 nets.

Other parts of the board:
C213: Opt_220u; CP_Radial_D10.0mm_P5.00mm
D211: LED; LED_0805_2012Metric
Q201, Q208, Q209, Q210: UMX1N; UMX1N_UMT6_DualNPN
RV201: 50k_emphasis; Potentiometer_China_RK09_Single_Vertical_AJ
RV202: 1k; Bourns3296WV
RV203: 50k_CV1; Potentiometer_China_RK09_Single_Vertical_AJ
RV204: 10k_Freq; Potentiometer_China_RK09_Single_Vertical_AJ
RV205: 500R; Bourns3296WV
RV206: 50k_CV2; Potentiometer_China_RK09_Single_Vertical_AJ
RV207: 10k; Bourns3296WV

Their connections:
+12V: Q201.3, Q201.6, RV207.1; also elsewhere on the board
/KicadJE_Yousynth_MoogVCF/Coupling: RV201.3; also elsewhere on the board
CV1: RV203.1; also elsewhere on the board
CV2: RV206.1; also elsewhere on the board
GND: C213.2, D211.2, RV203.3, RV204.3, RV205.2, RV205.3, RV206.3, RV207.3; also elsewhere on the board
unnamed 19: Q201.4; also elsewhere on the board
unnamed 20: Q201.1; also elsewhere on the board
unnamed 25: Q208.3; also elsewhere on the board
unnamed 26: Q208.6; also elsewhere on the board
unnamed 28: Q209.3, Q210.3; also elsewhere on the board
unnamed 29: Q208.2; also elsewhere on the board
unnamed 31: C213.1; also elsewhere on the board
unnamed 46: D211.1; also elsewhere on the board
unnamed 73: Q201.2, Q201.5; also elsewhere on the board
unnamed 77: Q208.1, Q208.4; also elsewhere on the board
unnamed: Q208.5, RV202.2
unnamed 79: Q209.1, Q210.2; also elsewhere on the board
unnamed 80: Q209.2; also elsewhere on the board
unnamed 81: Q209.4, Q210.5; also elsewhere on the board
unnamed 82: Q209.5; also elsewhere on the board
unnamed 83: Q209.6, Q210.6; also elsewhere on the board
unnamed 84: Q210.1, Q210.4; also elsewhere on the board
unnamed 96: RV201.1, RV202.1; also elsewhere on the board
unnamed 97: RV201.2; also elsewhere on the board
unnamed 102: RV202.3; also elsewhere on the board
unnamed 103: RV206.2; also elsewhere on the board
unnamed 104: RV204.1; also elsewhere on the board
unnamed 105: RV204.2; also elsewhere on the board
unnamed 106: RV205.1; also elsewhere on the board
unnamed 107: RV203.2; also elsewhere on the board
unnamed 108: RV207.2; also elsewhere on the board

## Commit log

2019-10-06 acq from Ate0Ate
    [KicadJE_AteOhAte2.sch, KicadJE_MoogVCF_1.kicad_pcb, KicadJE_MoogVCF_1.sch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]
2019-10-06 diff stage sch
    [KicadJE_Yousynth_MoogVCF.sch]
2019-10-06 Moog Output stage
    [KicadJE_Yousynth_MoogVCF.sch]
2019-10-06 Placing components
    [KicadJE_MoogVCF_1.kicad_pcb, KicadJE_Yousynth_MoogVCF.sch]
2019-10-06 fixing links
    [KicadJE_MoogVCF_1.kicad_pcb, KicadJE_Yousynth_MoogVCF.sch]
2019-10-06 placing input prot
    [KicadJE_MoogVCF_1.kicad_pcb]
2019-10-06 all components placed
    [KicadJE_Yousynth_MoogVCF.sch]
2019-10-06 Moog VCF complete
    [KicadJE_MoogVCF_1.kicad_pcb]
2019-10-06 Labels complete on Moog
    [KicadJE_MoogVCF_1.kicad_pcb]
2019-10-06 forgot a trimmer
    [KicadJE_Yousynth_MoogVCF.sch]
2019-10-06 Trim added to PCB
    [KicadJE_MoogVCF_1.kicad_pcb]
2019-10-06 Yousynth ADSR initiated
    [KicadJE_MoogVCF_1.sch, KicadJE_Yousynth_ADSR.sch, KicadJE_Yousynth_ADSR_empty.sch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]
2019-10-06 ADSR sch done
    [KicadJE_Yousynth_ADSR.sch]
2019-10-07 ADSR Routed
    [KicadJE_MoogVCF_1.kicad_pcb, KicadJE_Yousynth_ADSR.sch]
2019-10-07 Labels ADSR
    [KicadJE_MoogVCF_1.kicad_pcb]
2019-10-07 Wavefolder sch taking form
    [KicadJE_MoogVCF_1.sch, KicadJE_Yousynth_ADSR.sch, KicadJE_Yousynth_MoogVCF.sch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]
2019-10-07 Wavefolder annotated
    [KicadJE_Yousynth_WaveFolder.sch]
2019-10-07 ERC done
    [KicadJE_Yousynth_ADSR.sch, KicadJE_Yousynth_WaveFolder.sch]
2019-10-07 Fix power bug in ADSR TL072
    [KicadJE_MoogVCF_1.kicad_pcb]
2019-10-07 Folding Diode conn missing
    [KicadJE_MoogVCF_1.kicad_pcb, KicadJE_Yousynth_WaveFolder.sch]
2019-10-07 Routed Wavefolder
    [KicadJE_MoogVCF_1.kicad_pcb, _saved_KicadJE_Yousynth_WaveFolder.sch]
2019-10-07 Wavefolder labeled
    [KicadJE_MoogVCF_1.kicad_pcb, KicadJE_Yousynth_WaveFolder.sch, _saved_KicadJE_Yousynth_WaveFolder.sch]
2019-10-07 zip for jlc
    [KicadJE_MoogVCF_1-B_Cu.gbr, KicadJE_MoogVCF_1-B_Mask.gbr, KicadJE_MoogVCF_1-B_Paste.gbr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]
2019-10-07 remove excess btn
    [KicadJE_Yousynth_WaveFolder.sch]
2020-02-05 Review R-Open names after initial assembley - ADSR
    [KicadJE_MoogVCF_1.sch, KicadJE_Yousynth_ADSR.sch, KicadJE_Yousynth_MoogVCF.sch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]
2020-02-12 RevB
    Missing 2x 220N from filter to output :-S
    [KicadJE_AteOhAte2.sch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]
2020-02-15 revb update
    [KicadJE_Yousynth_MoogVCF_revB.sch, _saved_KicadJE_Yousynth_MoogVCF_revB.sch]
2021-05-17 Faceplate for Moog Filter
    [KicadJE_MoogVCF_1b.kicad_pcb]
2021-05-17 Wavefolder Faceplate
    [KicadJE_MoogVCF_1b.kicad_pcb]
2021-05-17 Update README.md
    KicadJE_MoogVCF_1_revB/KicadJE_MoogVCF_1b_Wavefolder_Front.png
